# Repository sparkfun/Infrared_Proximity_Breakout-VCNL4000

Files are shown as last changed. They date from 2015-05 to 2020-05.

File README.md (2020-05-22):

**NOTE:** *This product has been retired from our catalog. If you are looking for more up-to-date info, please check out some of these resources to see how other users are still hacking and improving on this product.*
* *[SparkFun Forum](https://forum.sparkfun.com/)*
* *[Comments Here on GitHub](https://github.com/sparkfun/Infrared_Proximity_Breakout-VCNL4000/issues)*

SparkFun Infrared Proximity Breakout - VCNL4000
========================================

SparkFun Infrared Proximity Breakout - VCNL4000

[*SparkFun Infrared Proximity Breakout - VCNL4000 (BOB-10901)*](https://www.sparkfun.com/products/10901)

The VCNL4000 can detect its proximity to an object using IR within a range of about 20cm. 
Proximity data as well as ambient light level data can be collected over an I2C interface.

Repository Contents
-------------------

* **/Firmware** - Example Arduino code 
* **/Hardware** - Eagle design files (.brd, .sch)
* **/Production** - Production panel files (.brd)

Documentation
--------------
* **[SparkFun Fritzing repo](https://github.com/sparkfun/Fritzing_Parts)** - Fritzing diagrams for SparkFun products.
* **[SparkFun 3D Model repo](https://github.com/sparkfun/3D_Models)** - 3D models of SparkFun products. 

License Information
-------------------
This product is _**open source**_! 

The **hardware** is released under [Creative Commons ShareAlike 4.0 International](https://creativecommons.org/licenses/by-sa/4.0/).

The **code** is beerware; if you see me (or any other SparkFun employee) at the local, and you've found our code helpful, please buy us a round!

Please use, reuse, and modify these files as you see fit. Please maintain attribution to SparkFun Electronics and release anything derivative under the same license.

Distributed as-is; no warranty is given.

- Your friends at SparkFun.

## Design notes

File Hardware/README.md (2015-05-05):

SparkFun <PRODUCT NAME> Design Files
=====================================

The .sch and .brd files hare are Eagle CAD schematic and PCB design files from SparkFun Electronics.
A freeware version of Eagle can be found [here](http://www.cadsoftusa.com/download-eagle/freeware/). 

License
---------
This product is open source! 
The hardware is released under [Creative Commons ShareAlike 4.0 International](https://creativecommons.org/licenses/by-sa/4.0/).

Please use, reuse, and modify these files as you see fit. Please maintain attribution to SparkFun Electronics and release anything derivative under the same license.

Distributed as-is; no warranty is given.

- Your friends at SparkFun.

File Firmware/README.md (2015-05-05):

SparkFun VCNL4000 Firmware
===================================

* **SparkFunVCNL4000Example** - Arduino example sketch.

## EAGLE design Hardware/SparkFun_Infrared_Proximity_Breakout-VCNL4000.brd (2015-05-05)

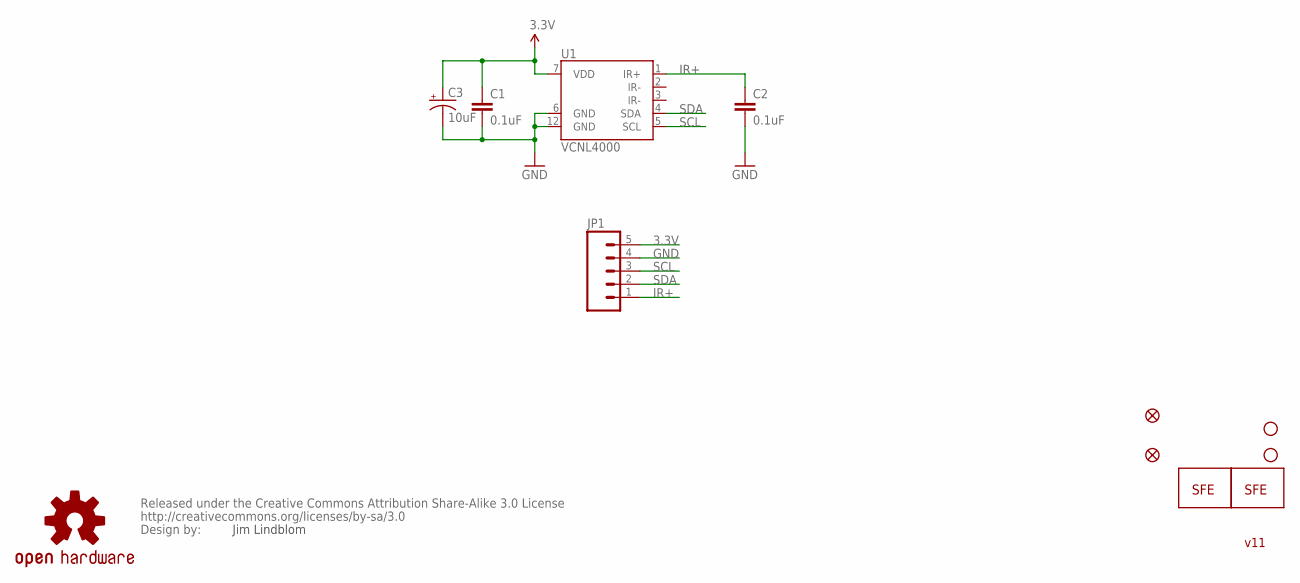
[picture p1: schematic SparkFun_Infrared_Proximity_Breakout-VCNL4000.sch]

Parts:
C1, C2: 0.1uF; 0402-CAP
C3: 10uF; EIA3216
JP1: M05PTH; 1X05
JP2: LOGO-SFENW2; SFE-NEW-WEB
JP3, JP4: STAND-OFF
JP5: LOGO-SFESK; SFE-LOGO-FLAME
JP6, JP7: FIDUCIALUFIDUCIAL; MICRO-FIDUCIAL
U1: VCNL4000
U$1: OSHW-LOGOS; OSHW-LOGO-S
U$2: CREATIVE_COMMONS

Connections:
3.3V: C1.1, C3.A (+), JP1.5, U1.7 (VDD)
GND: C1.2, C2.2, C3.C (-), JP1.4, U1.6 (GND), U1.12 (GND)
IR+: C2.1, JP1.1, U1.1 (IR+)
SCL: JP1.3, U1.5 (SCL)
SDA: JP1.2, U1.4 (SDA)

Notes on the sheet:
Jim Lindblom
v11

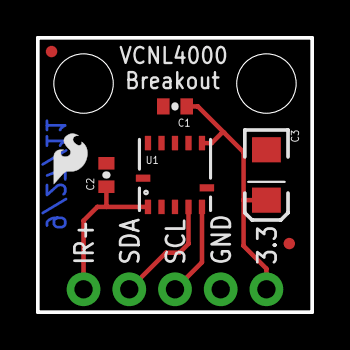
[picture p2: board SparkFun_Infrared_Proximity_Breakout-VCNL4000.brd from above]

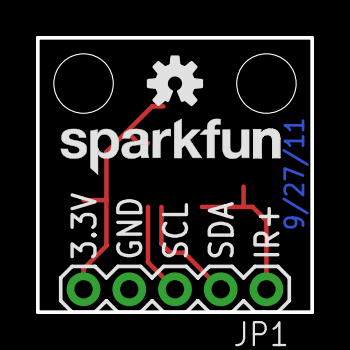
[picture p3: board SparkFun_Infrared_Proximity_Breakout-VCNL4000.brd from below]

Board: 2 copper layers, 15.2 x 15.2 mm, 13 parts (3 on the bottom side), 5 nets.

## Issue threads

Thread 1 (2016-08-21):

No need to wait for data after Wire.requestFrom()

Koepel, 2016-08-21:
There is no need to wait for data after the call to Wire.requestFrom().
When the function Wire.requestFrom() returns, the I2C transaction has completely finished and the received data is waiting in the buffer in the Wire library.

bboyho, 2020-05-22:
Hi,

Sorry for the delay in reply. I was browsing some issues when I noticed this issue that was filed. When the code was originally written, I don't believe that we were aware of the [common mistakes that came with using the Wire library](https://github.com/Koepel/How-to-use-the-Arduino-Wire-library/wiki/Common-mistakes#1).

I have [removed the line](https://github.com/sparkfun/Infrared_Proximity_Breakout-VCNL4000/commit/90bc6496469964f7fe3b7638f1a1f328e87f960d).

Closed 2020-05-22.

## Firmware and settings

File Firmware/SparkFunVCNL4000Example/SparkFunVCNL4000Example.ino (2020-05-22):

/* VCNL4000 Proximity and Ambient Light Sensor
   Example Code
   by: Jim Lindblom
   SparkFun Electronics
   date: August 30, 2011 (updated November 3, 2011)
   license: Beerware - Use this code however you want. If you find
   it useful you can by me a beer someday.
   
   There are a lot of parameters that you can play with on this sensor:
   * IR LED current: this can range from 0 (0mA, off) to 20 (200mA). Increase IR current, 
   and you increase the sensitivity. Write to the IR_CURRENT register to adjust this
   value.
   * Ambient Light Parameter: You can adjust the number of measurements that are
   averaged into one output. By default the code averages the maximum, 128. Write to
   the AMBIENT_PARAMETER to change this value.
   * Proximity Signal Frequency: The frequency of the IR test signal can be either
   3.125 MHZ, 1.5625 MHz, 781.25 kHz, or 390.625kHz. Writing a 0, 1, 2, or 3 to the 
   PROXIMITY_FREQ register will set this. The code sets it to 781.25 kHz by default.
   * Modulation delay and dead time: Not a lot of info in the datasheet on how
   to adjust these values. Write to the PROXIMITY_MOD register to change them. By 
   default this register is set to 0x81 (129) as recommended by Vishay.
   
   Try to optimize the sensor for your application. Play around with those parameters.
   
   The sensor gets more and more sensitive as an object gets closer to it. The proximity
   output does not share a linear relationship with distance. The max distance is about
   20cm. Minimum distance is a few mm.
   
   Hardware:
   This code was developed using the SparkFun breakout board:
   http://www.sparkfun.com/products/10901
   Connections are:
   VCNL4000 Breakout ---------------- Arduino
        3.3V  -----------------------  3.3V
        GND  ------------------------  GND
        SCL  ------------------------  A5
        SDA  ------------------------  A4
        IR+  ------------------------  5V (3.3V is fine too)
 */
#include <Wire.h>

#define VCNL4000_ADDRESS 0x13  // 0x26 write, 0x27 read

// VCNL4000 Register Map
#define COMMAND_0 0x80  // starts measurments, relays data ready info
#define PRODUCT_ID 0x81  // product ID/revision ID, should read 0x11
#define IR_CURRENT 0x83  // sets IR current in steps of 10mA 0-200mA
#define AMBIENT_PARAMETER 0x84  // Configures ambient light measures
#define AMBIENT_RESULT_MSB 0x85  // high byte of ambient light measure
#define AMBIENT_RESULT_LSB 0x86  // low byte of ambient light measure
#define PROXIMITY_RESULT_MSB 0x87  // High byte of proximity measure
#define PROXIMITY_RESULT_LSB 0x88  // low byte of proximity measure
#define PROXIMITY_FREQ 0x89  // Proximity IR test signal freq, 0-3
#define PROXIMITY_MOD 0x8A  // proximity modulator timing

int ambientValue, proximityValue;

void setup()
{
  Serial.begin(9600);  // Serial's used to debug and print data
  Wire.begin();  // initialize I2C stuff
  
  /* Test that the device is working correctly */
  byte temp = readByte(PRODUCT_ID);
  if (temp != 0x11)  // Product ID Should be 0x11
  {
    Serial.print("Something's wrong. Not reading correct ID: 0x");
    Serial.println(temp, HEX);
  }
  else
    Serial.println("VNCL4000 Online...");
  
  /* Now some VNCL400 initialization stuff
     Feel free to play with any of these values, but check the datasheet first!*/
  writeByte(AMBIENT_PARAMETER, 0x0F);  // Single conversion mode, 128 averages
  writeByte(IR_CURRENT, 20);  // Set IR current to 200mA
  writeByte(PROXIMITY_FREQ, 2);  // 781.25 kHz
  writeByte(PROXIMITY_MOD, 0x81);  // 129, recommended by Vishay
}

void loop()
{
  /* The loop just continuously reads the ambient and proximity values
  and spits them out over serial. */
  ambientValue = readAmbient();
  proximityValue = readProximity();
  Serial.print(ambientValue, DEC);
  Serial.print("\t");
  Serial.println(proximityValue, DEC);
  // delay(100);  // You may want to uncomment this for visibility
}

// readProximity() returns a 16-bit value from the VCNL4000's proximity data registers
unsigned int readProximity()
{
  unsigned int data;
  byte temp;
  
  temp = readByte(COMMAND_0);
  writeByte(COMMAND_0, temp | 0x08);  // command the sensor to perform a proximity measure
  
  while(!(readByte(COMMAND_0)&0x20)) 
    ;  // Wait for the proximity data ready bit to be set
  data = readByte(PROXIMITY_RESULT_MSB) << 8;
  data |= readByte(PROXIMITY_RESULT_LSB);
  
  return data;
}

// readAmbient() returns a 16-bit value from the VCNL4000's ambient light data registers
unsigned int readAmbient()
{
  unsigned int data;
  byte temp;
  
  temp = readByte(COMMAND_0);
  writeByte(COMMAND_0, temp | 0x10);  // command the sensor to perform ambient measure
  
  while(!(readByte(COMMAND_0)&0x40)) 
    ;  // wait for the proximity data ready bit to be set
  data = readByte(AMBIENT_RESULT_MSB) << 8;
  data |= readByte(AMBIENT_RESULT_LSB);
  
  return data;
}

// writeByte(address, data) writes a single byte of data to address
void writeByte(byte address, byte data)
{
  Wire.beginTransmission(VCNL4000_ADDRESS);
  Wire.write(address);
  Wire.write(data);
  Wire.endTransmission();
}

// readByte(address) reads a single byte of data from address
byte readByte(byte address)
{
  byte data;
  
  Wire.beginTransmission(VCNL4000_ADDRESS);
  Wire.write(address);
  Wire.endTransmission();
  Wire.requestFrom(VCNL4000_ADDRESS, 1);
  data = Wire.read();

  return data;
}

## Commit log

2015-05-05 Adding hardware
    [SparkFun_Infrared_Proximity_Breakout-VCNL4000.brd, SparkFun_Infrared_Proximity_Breakout-VCNL4000.sch]
2020-05-22 Update SparkFunVCNL4000Example.ino
    Removing line [based on feedback](https://github.com/sparkfun/Infrared_Proximity_Breakout-VCNL4000/issues/1).
    [SparkFunVCNL4000Example.ino]

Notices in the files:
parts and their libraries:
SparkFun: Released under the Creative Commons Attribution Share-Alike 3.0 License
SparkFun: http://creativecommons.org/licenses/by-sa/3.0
